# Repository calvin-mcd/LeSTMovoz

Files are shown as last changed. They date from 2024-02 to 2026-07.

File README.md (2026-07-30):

# LeSTMovoz
 
The LeSTMovoz is drop-in DIY replacement pcb for the [Lesovoz](https://trashman.wiki/community/pcbs/lesovoz) pcb by squash for [minivan](https://trashman.wiki/) style cases.
The replacement pcb adds a second 2u bottom row option by omitting one tray mount hole. [Existing plates](https://www.minivanplate.xyz/) should work but said 2u option is not accounted for in original plates.  

It uses mostly THT components to be added by hand, but production files exist to handle the few SMD components (STM32 mcu, logic shifter for rgb, usb port) with factory assembly.

Vial Firmware was created by JLW and can be found here: https://github.com/josh-l-wang/vial-qmk/tree/main-vial/keyboards/jlw/lestmovoz

## Layout

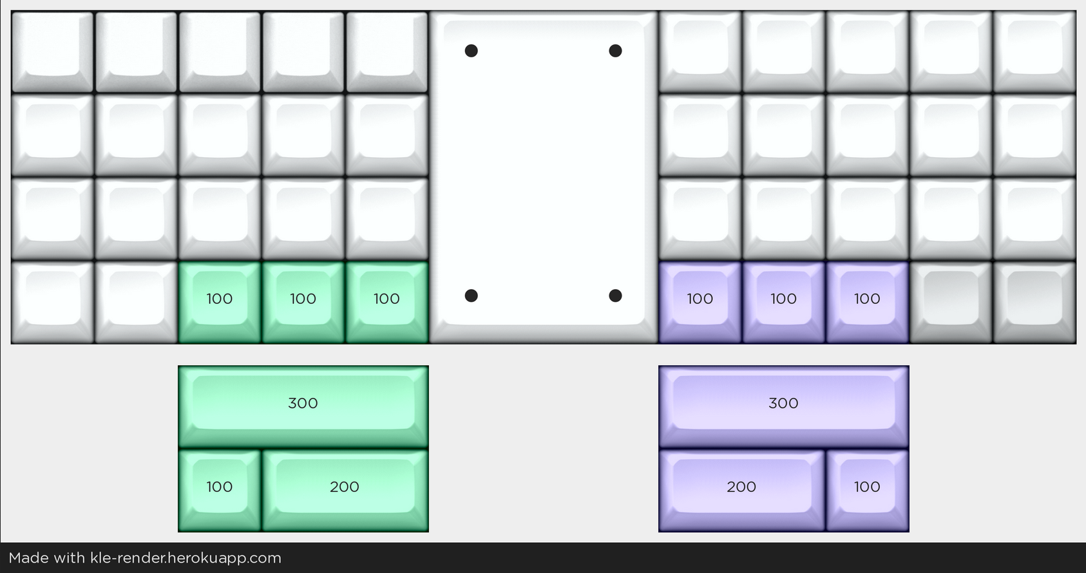
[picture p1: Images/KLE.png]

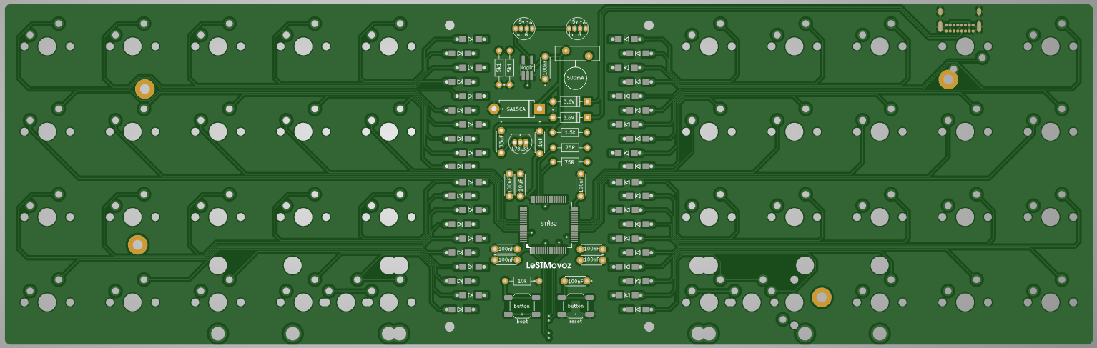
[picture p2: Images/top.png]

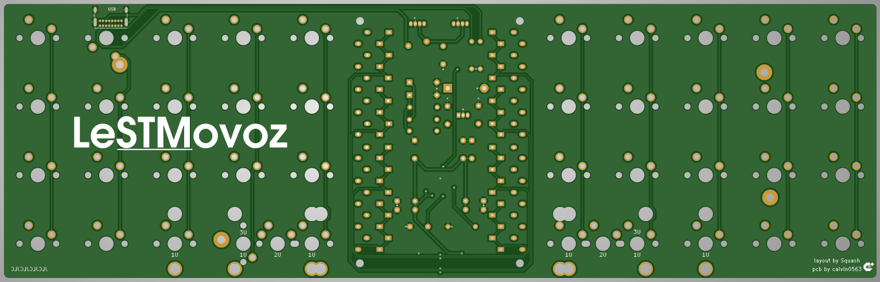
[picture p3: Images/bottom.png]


[Link](http://www.keyboard-layout-editor.com/#/gists/4bbcc5860d075f44de381a1146810c87)

## Todo

- [x] order & test pcb Rev 2
- [x] create firmware

## Disclaimer

This PCB has been fully tested and is confirmed to work. However, no-one involved in this project is responsible for any usage issues that may arise. Order at your own risk. Feel free to edit, modify and otherwise utilise these files.

## License

This project is released under the GPL v3 License. Please refer to the LICENCE file.

## Credits

Big thanks to JLW for supporting and making this project possible and to Kenny for getting it out there to people.

And as always big thanks to the 40s community!

Any questions, contact calvin0563 on Discord.

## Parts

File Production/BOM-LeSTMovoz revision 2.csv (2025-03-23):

Comment | Designator | Footprint | LCSC | Quantity
74AHCT1G125 | U3 | TSOT-23-5_HandSoldering | C12494 | 1
USB_C_Receptacle_USB2.0 | J1 | USB_C_Receptacle_HRO_TYPE-C-31-M-12 | C165948 | 1
STM32F072RBTx | U1 | LQFP-64_10x10mm_P0.5mm | C46046 | 1

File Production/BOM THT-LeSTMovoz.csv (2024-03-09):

Comment | Designator | Amount | Footprint | LCSC
SW_SPST | RST1,SW1 | 2 | SW_SPST_SKQG_WithStem | C115351
74AHCT1G125 | U3 | 1 | TSOT-23-5_HandSoldering | C12494
STM32F072RBTx | U1 | 1 | LQFP-64_10x10mm_P0.5mm | C46046
500mA | F1 | 1 | Fuse_Bourns_MF-RHT100 | C1562377
100nF | C3, C4, C5, C6, C7, C8, C9, C12 | 8 | C_Disc_D4.3mm_W1.9mm_P5.00mm | C527620
5k1 | R4, R5 | 2 | R_Axial_DIN0204_L3.6mm_D1.6mm_P7.62mm_Horizontal | C1370648
75R | R2, R3 | 2 | R_Axial_DIN0204_L3.6mm_D1.6mm_P7.62mm_Horizontal | C3495384
0.33uF | C1 | 1 | C_Disc_D4.3mm_W1.9mm_P5.00mm | C454409
SA15CA | D41 | 1 | D_DO-15_P10.16mm_Horizontal | C7466191
1.5k | R1 | 1 | R_Axial_DIN0204_L3.6mm_D1.6mm_P7.62mm_Horizontal | C1369547
3.6V | D42, D43 | 2 | D_DO-35_SOD27_P7.62mm_Horizontal | C895320
L78L33_TO92 | U2 | 1 | TO-92_Inline | C2927581
10uF | C10 | 1 | C_Disc_D4.3mm_W1.9mm_P5.00mm | C454408
10k | R6 | 1 | R_Axial_DIN0204_L3.6mm_D1.6mm_P7.62mm_Horizontal | C1420778
1uF | C2 | 1 | C_Disc_D4.3mm_W1.9mm_P5.00mm | C454378
USB_C_Receptacle_USB2.0 | J1 | 1 | USB_C_Receptacle_GCT_USB4085 | C2840393
WS2812B | D44, D45 | 2 | WS2812B | C190565
D3_TH_SMD_v2 | D1 – D40 | 40 |  | C85057
 |  |  |  | C402212

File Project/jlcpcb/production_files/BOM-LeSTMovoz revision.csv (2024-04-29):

Comment | Designator | Footprint | LCSC
74AHCT1G125 | U3 | TSOT-23-5_HandSoldering | C12494
STM32F072RBTx | U1 | LQFP-64_10x10mm_P0.5mm | C46046

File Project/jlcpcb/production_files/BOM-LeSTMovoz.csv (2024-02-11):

Comment | Designator | Footprint | LCSC
SW_SPST | RST1,SW1 | SW_SPST_SKQG_WithStem | C115351
74AHCT1G125 | U3 | TSOT-23-5_HandSoldering | C12494
STM32F072RBTx | U1 | LQFP-64_10x10mm_P0.5mm | C46046

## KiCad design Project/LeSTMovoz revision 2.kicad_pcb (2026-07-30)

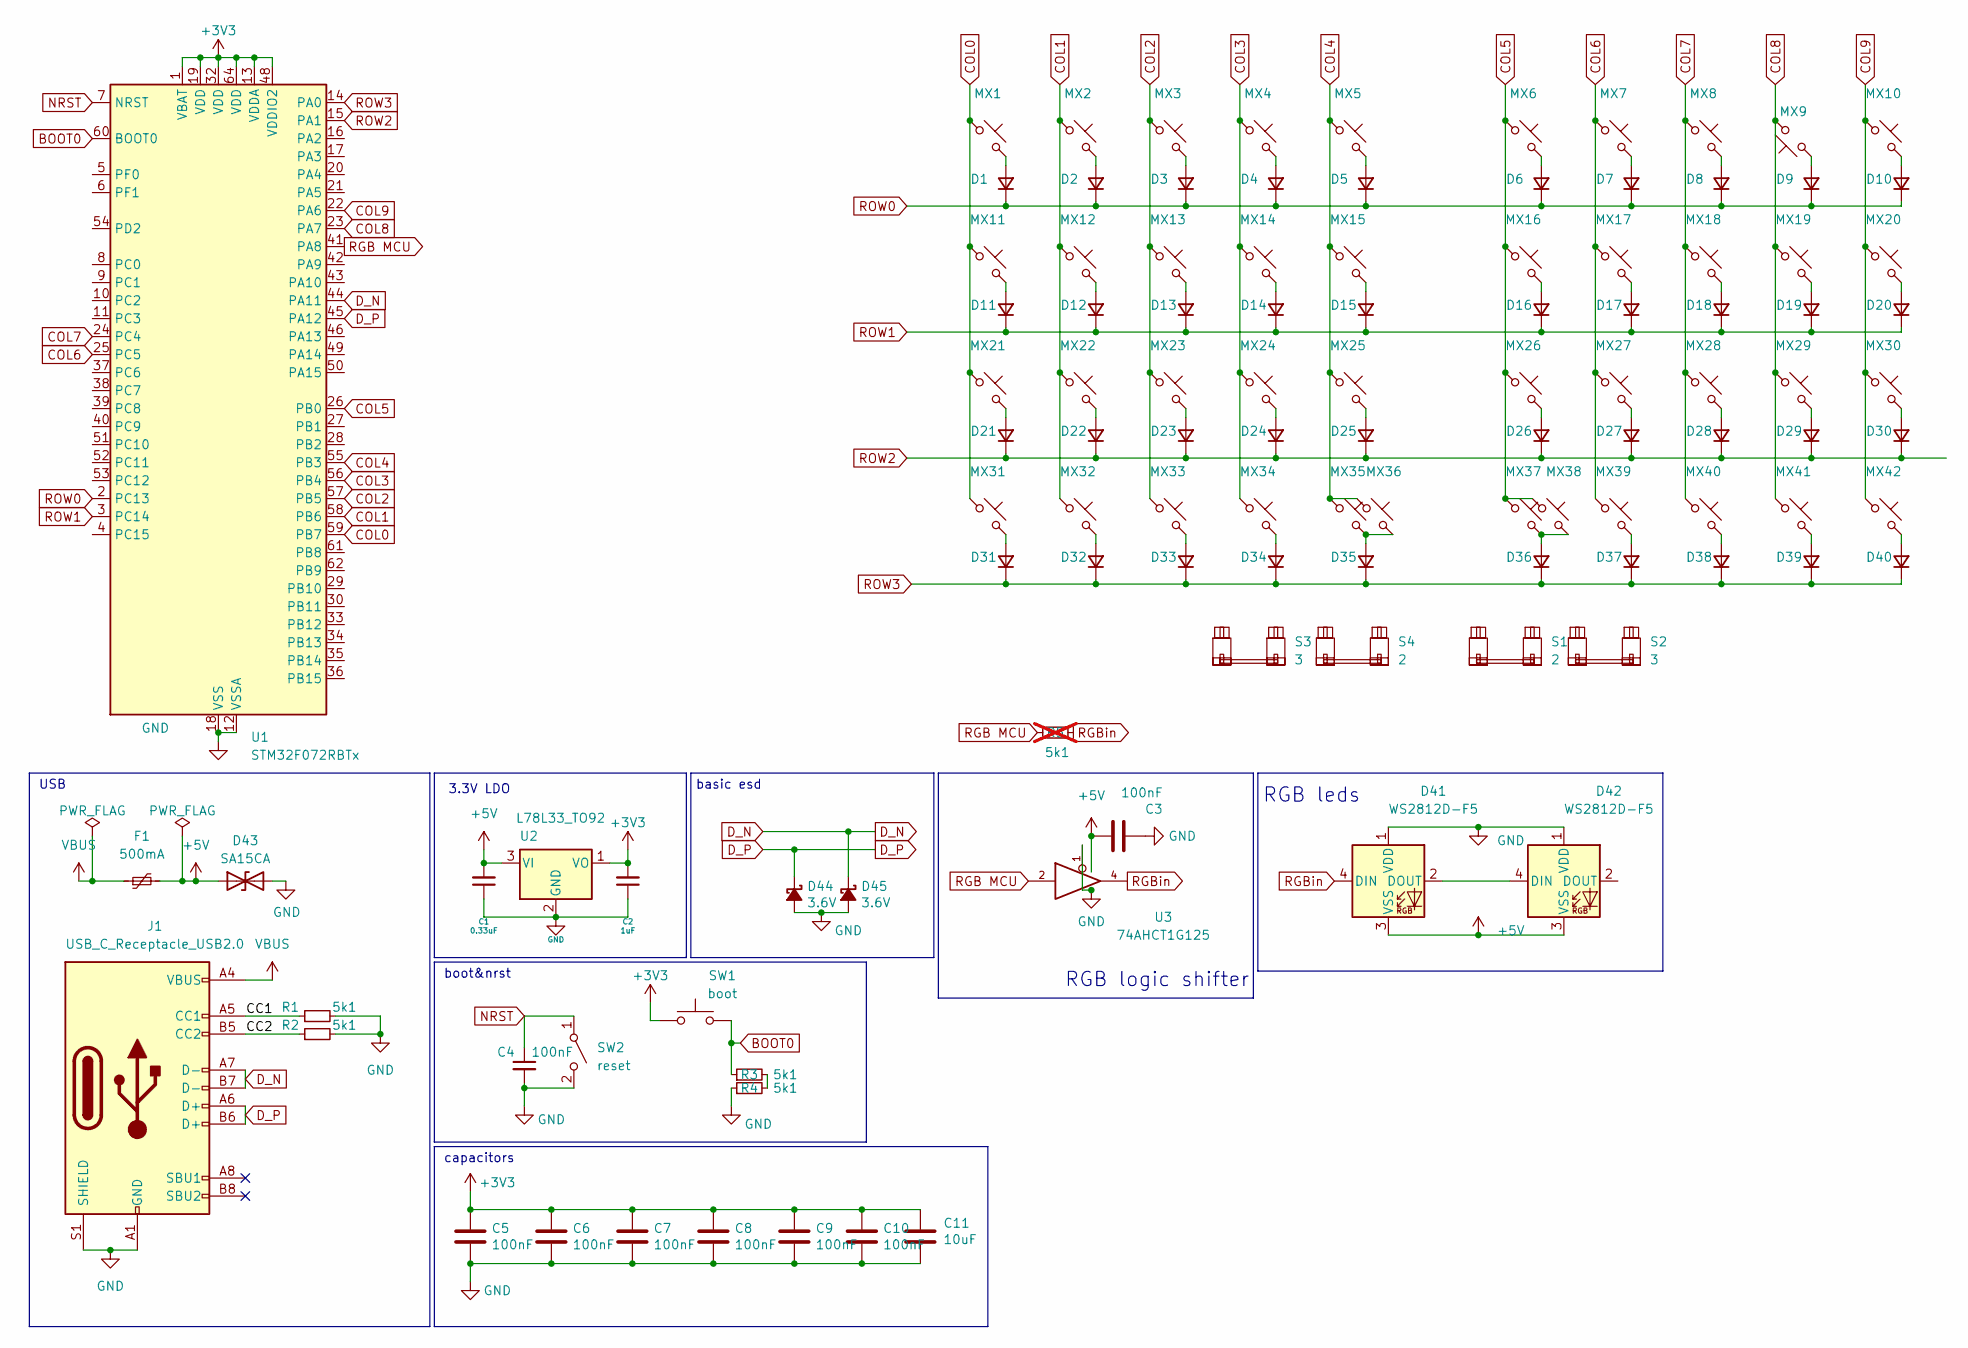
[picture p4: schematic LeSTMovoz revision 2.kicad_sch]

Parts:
C1: 0.33uF; C_Disc_D4.3mm_W1.9mm_P5.00mm
C2: 1uF; C_Disc_D4.3mm_W1.9mm_P5.00mm
C3, C4, C5, C6, C7, C8, C9, C10: 100nF; C_Disc_D4.3mm_W1.9mm_P5.00mm
C11: 10uF; C_Disc_D4.3mm_W1.9mm_P5.00mm
D1, D2, D3, D4, D5, D6, D7, D8, D9, D10, D11, D12, D13, D14, D15, D16, D17, D18, D19, D20, D21, D22, D23, D24, D25, D26, D27, D28, D29, D30, D31, D32, D33, D34, D35, D36, D37, D38, D39, D40: D_Small; D3_TH_SMD_v3
D41, D42: WS2812D-F5; NeoPixel_bulb_5mm_Adafruit_1938
D43: SA15CA; D_DO-15_P10.16mm_Horizontal
D44, D45: 3.6V; D_DO-35_SOD27_P7.62mm_Horizontal
F1: 500mA; Fuse_Bourns_MF-RHT100
J1: USB_C_Receptacle_USB2.0; USB_C_Receptacle_HRO_TYPE-C-31-M-12; LCSC C165948
MX1, MX2, MX3, MX4, MX5, MX6, MX7, MX8, MX9, MX10, MX11, MX12, MX13, MX14, MX15, MX16, MX17, MX18, MX19, MX20, MX21, MX22, MX23, MX24, MX25, MX26, MX27, MX28, MX29, MX30, MX31, MX32, MX33, MX34, MX35, MX36, MX37, MX38, MX39, MX40, MX41, MX42: MX_SW_solder; MX-Alps-Hybrid-1U
R1, R2, R3, R4: 5k1; R_Axial_DIN0204_L3.6mm_D1.6mm_P7.62mm_Horizontal
R5: 5k1; R_Axial_DIN0204_L3.6mm_D1.6mm_P7.62mm_Horizontal; not fitted
S1, S4: 2; STAB_MX_P_2u
S2, S3: 3; STAB_MX_P_3u
SW1: boot; SW_PUSH_6mm_H4.3mm; LCSC C115351
SW2: reset; SW_PUSH_6mm_H4.3mm; LCSC C115351
U1: STM32F072RBTx; LQFP-64_10x10mm_P0.5mm
U2: L78L33_TO92; TO-92_Inline
U3: 74AHCT1G125; TSOT-23-5_HandSoldering; LCSC C12494

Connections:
+3V3: C2.2, C5.1, C6.1, C7.1, C8.1, C9.1, C10.1, C11.1, SW1.1, U1.1 (VBAT), U1.13 (VDDA), U1.19 (VDD), U1.32 (VDD), U1.48 (VDDIO2), U1.64 (VDD), U2.1 (VO)
+5V: C1.2, C3.1, D41.3 (VSS), D42.3 (VSS), D43.1 (A1), F1.2, U2.3 (VI), U3.5 (+5V)
/CC1: J1.A5 (CC1), R1.1
/CC2: J1.B5 (CC2), R2.1
BOOT0: R3.1, SW1.2, U1.60 (BOOT0)
COL0: MX1.1, MX11.1, MX21.1, MX31.1, U1.59 (PB7)
COL1: MX2.1, MX12.1, MX22.1, MX32.1, U1.58 (PB6)
COL2: MX3.1, MX13.1, MX23.1, MX33.1, U1.57 (PB5)
COL3: MX4.1, MX14.1, MX24.1, MX34.1, U1.56 (PB4)
COL4: MX5.1, MX15.1, MX25.1, MX35.1, MX36.1, U1.55 (PB3)
COL5: MX6.1, MX16.1, MX26.1, MX37.1, MX38.1, U1.26 (PB0)
COL6: MX7.1, MX17.1, MX27.1, MX39.1, U1.25 (PC5)
COL7: MX8.1, MX18.1, MX28.1, MX40.1, U1.24 (PC4)
COL8: MX9.2, MX19.1, MX29.1, MX41.1, U1.23 (PA7)
COL9: MX10.1, MX20.1, MX30.1, MX42.1, U1.22 (PA6)
D_N: D45.1 (K), J1.A7 (D-), J1.B7 (D-), U1.44 (PA11)
D_P: D44.1 (K), J1.A6 (D+), J1.B6 (D+), U1.45 (PA12)
GND: C1.1, C2.1, C3.2, C4.2, C5.2, C6.2, C7.2, C8.2, C9.2, C10.2, C11.2, D41.1 (VDD), D42.1 (VDD), D43.2 (A2), D44.2 (A), D45.2 (A), J1.A1 (GND), J1.A12 (GND), J1.B1 (GND), J1.B12 (GND), J1.S1 (SHIELD), R1.2, R2.2, R4.1, SW2.2 (B), U1.12 (VSSA), U1.18 (VSS), U1.31 (VSS), U1.47 (VSS), U1.63 (VSS), U2.2 (GND), U3.1, U3.3 (GND)
NRST: C4.1, SW2.1 (A), U1.7 (NRST)
unnamed: D1.2 (A), MX1.2
unnamed: D2.2 (A), MX2.2
unnamed: D3.2 (A), MX3.2
unnamed: D4.2 (A), MX4.2
unnamed: D5.2 (A), MX5.2
unnamed: D6.2 (A), MX6.2
unnamed: D7.2 (A), MX7.2
unnamed: D8.2 (A), MX8.2
unnamed: D9.2 (A), MX9.1
unnamed: D10.2 (A), MX10.2
unnamed: D11.2 (A), MX11.2
unnamed: D12.2 (A), MX12.2
unnamed: D13.2 (A), MX13.2
unnamed: D14.2 (A), MX14.2
unnamed: D15.2 (A), MX15.2
unnamed: D16.2 (A), MX16.2
unnamed: D17.2 (A), MX17.2
unnamed: D18.2 (A), MX18.2
unnamed: D19.2 (A), MX19.2
unnamed: D20.2 (A), MX20.2
unnamed: D21.2 (A), MX21.2
unnamed: D22.2 (A), MX22.2
unnamed: D23.2 (A), MX23.2
unnamed: D24.2 (A), MX24.2
unnamed: D25.2 (A), MX25.2
unnamed: D26.2 (A), MX26.2
unnamed: D27.2 (A), MX27.2
unnamed: D28.2 (A), MX28.2
unnamed: D29.2 (A), MX29.2
unnamed: D30.2 (A), MX30.2
unnamed: D31.2 (A), MX31.2
unnamed: D32.2 (A), MX32.2
unnamed: D33.2 (A), MX33.2
unnamed: D34.2 (A), MX34.2
unnamed: D35.2 (A), MX35.2, MX36.2
unnamed: D36.2 (A), MX37.2, MX38.2
unnamed: D37.2 (A), MX39.2
unnamed: D38.2 (A), MX40.2
unnamed: D39.2 (A), MX41.2
unnamed: D40.2 (A), MX42.2
unnamed: D41.2 (DOUT), D42.4 (DIN)
unnamed: R3.2, R4.2
RGB MCU: R5.1, U1.41 (PA8), U3.2
RGBin: D41.4 (DIN), R5.2, U3.4
ROW0: D1.1 (K), D2.1 (K), D3.1 (K), D4.1 (K), D5.1 (K), D6.1 (K), D7.1 (K), D8.1 (K), D9.1 (K), D10.1 (K), U1.2 (PC13)
ROW1: D11.1 (K), D12.1 (K), D13.1 (K), D14.1 (K), D15.1 (K), D16.1 (K), D17.1 (K), D18.1 (K), D19.1 (K), D20.1 (K), U1.3 (PC14)
ROW2: D21.1 (K), D22.1 (K), D23.1 (K), D24.1 (K), D25.1 (K), D26.1 (K), D27.1 (K), D28.1 (K), D29.1 (K), D30.1 (K), U1.15 (PA1)
ROW3: D31.1 (K), D32.1 (K), D33.1 (K), D34.1 (K), D35.1 (K), D36.1 (K), D37.1 (K), D38.1 (K), D39.1 (K), D40.1 (K), U1.14 (PA0)
VBUS: F1.1, J1.A4 (VBUS), J1.A9 (VBUS), J1.B4 (VBUS), J1.B9 (VBUS)

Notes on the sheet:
RGB leds
RGB logic shifter
capacitors
boot&nrst
3.3V LDO
USB
basic esd

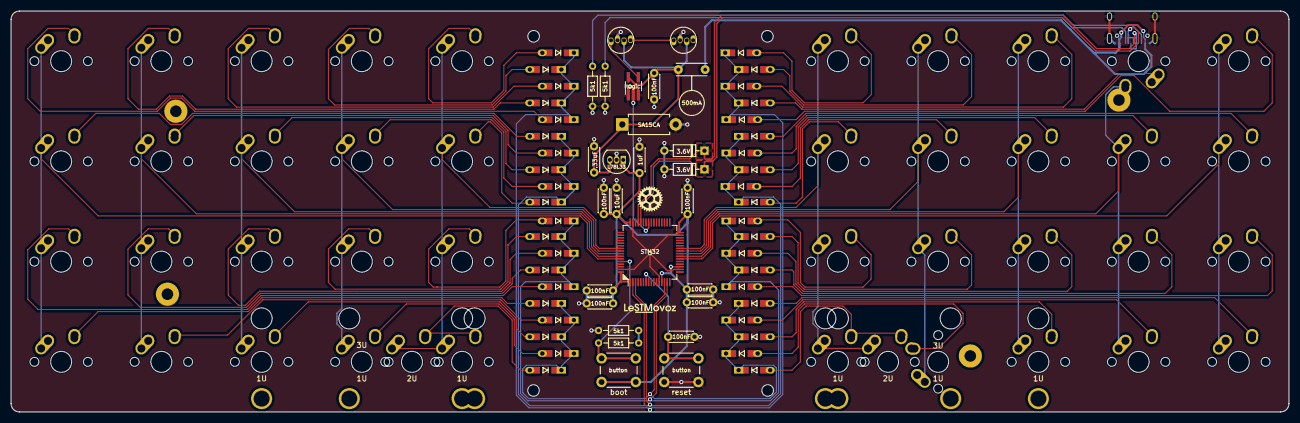
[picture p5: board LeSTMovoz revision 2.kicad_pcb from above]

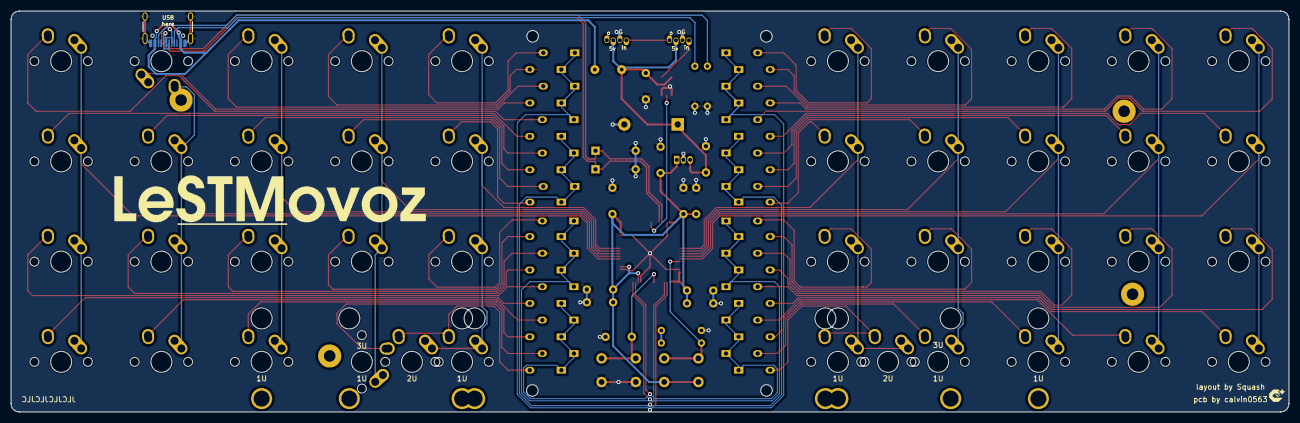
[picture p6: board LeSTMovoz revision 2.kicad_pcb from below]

Board: 2 copper layers, 242.9 x 76.2 mm, 114 parts (3 on the bottom side), 68 nets.

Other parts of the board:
H6: MountingHole_Pad; MountingHole_2.2mm_M2_Pad

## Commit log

2024-02-11 initialise, add pictures, update readme
    [BOM-LeSTMovoz.csv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]
2024-02-23 fresh gerbers
    [BOM-LeSTMovoz.csv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]
2024-03-09 changed rgb component, 10k for 2*5k1 resistors, finished THT BOM
    [BOM THT-LeSTMovoz.csv, BOM-LeSTMovoz.csv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]
2024-03-30 backups of revision work
    [LeSTMovoz revision 1.kicad_pcb, LeSTMovoz revision 1.kicad_sch, LeSTMovoz revision 2.kicad_pcb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]
2024-04-13 revision wip
    [LeSTMovoz revision 2.kicad_pcb, LeSTMovoz revision 2.kicad_sch]
2024-04-29 gerbers for revision
    [BOM-LeSTMovoz revision.csv, LeSTMovoz revision 1.kicad_pcb, LeSTMovoz revision 1.kicad_sch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]
2024-09-04 Update LeSTMovoz revision.kicad_prl
2025-03-01 revison work
    [LeSTMovoz revision 2.kicad_pcb, LeSTMovoz revision 2.kicad_sch, LeSTMovoz.kicad_sch]
2025-03-23 production files
    [BOM-LeSTMovoz revision 2.csv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]
2026-07-30 production files cleaned up
    [BOM-LeSTMovoz revision 2.csv, BOM-LeSTMovoz.csv, LeSTMovoz revision 2.kicad_pcb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]
